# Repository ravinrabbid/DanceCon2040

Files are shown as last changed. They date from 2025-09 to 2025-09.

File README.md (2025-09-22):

# DanceCon2040 - A RP2040 based Dance Pad

DanceCon2040 is a firmware (and by extension a PCB) for arcade style Dance Pad controllers with up to nine panels.

It is pretty much tailored to this specific use case, if you are looking for something universal, ready-to-flash and on-the-fly configurable I'd recommend to have a look at more generic approaches like [GP2040-CE](https://github.com/OpenStickCommunity/GP2040-CE). If you however want build something more specialized or custom, feel free to use this project as a base, it is designed to be somewhat modular and should be easy remodel. See [DivaCon2040](https://github.com/ravinrabbid/DivaCon2040) or [DonCon2040](https://github.com/ravinrabbid/DonCon2040) for examples on how this could look like.
If you have any questions about the project in general or need hints how to build this thing, feel free to open a [discussion](https://github.com/ravinrabbid/DanceCon2040/discussions) anytime!

## Features

- Various controller emulation modes
  - Spice2x - Basic USB gamepad with support for HID lights
  - Xbox360 DDR - Emulates a Xbox360 DDR Dance Mat (untested!)
  - Xbox360
  - PS3 DDR - Emulates a Playstation 3 DDR Dance Mat
  - Dualshock 3
  - Dualshock 4 (Only for PC/Steam, does not work on an actual PS4!)
  - PS4 Compat - Works on PS4 (see [PS4 Authentication](#ps4-authentication) for details)
  - Switch Pro Controller
  - Keyboard - Two different mappings for player 1 or 2 available
  - Debug mode - Outputs current state via USB serial and allows direct flashing
- Support for either 4,5,6,8 or 9 panels for different games/game modes.
- Additional buttons via external i2c GPIO expander
- Basic configuration via on-screen menu on attached OLED screen
- WS2812 LED for panel illumination
- Steps-per-minute counter counter on display

## Building

<!-- I highly recommend to build the firmware yourself so you can make adjustments in `include/GlobalConfiguration.h` to match your specific controller build.
You can still use the [binary release](https://github.com/ravinrabbid/DanceCon2040/releases) which is pre-configured for the [DanceConIO](/pcb/DanceConIO). -->

### VSCode (Windows, Linux, MacOS)

Install [VSCode](https://code.visualstudio.com/) and get the [Raspberry Pi Pico](https://marketplace.visualstudio.com/items?itemName=raspberry-pi.raspberry-pi-pico) extension. From the extension choose 'Import Project' and select the folder where you've checked out this repository, then use 'Compile Project'.

### CLI

See [pico-sdk readme](https://github.com/raspberrypi/pico-sdk/blob/master/README.md#quick-start-your-own-project) for a list of pre-requisites.

Use the environment variables `PICO_SDK_PATH` to use a local pico-sdk, and `PICO_BOARD` to select another target board.
By default the pico-sdk will be fetched from Github and the target board will be "pico".

```sh
mkdir build && cd build
cmake ..
make
```

## Configuration

Few things which you probably want to change more regularly can be changed using an on-screen menu on the attached OLED display, hold both Start and Select for 2 seconds to enter the menu:

- Controller emulation mode
- Trigger thresholds
- Hold Time
- Hysteresis
- Calibration
- LED brightness, animation style and colors
- Reset settings to defaults
- Enter BOOTSEL mode for firmware flashing

Those settings are persisted to flash memory if you choose 'Save' when exiting the Menu and will survive power cycles.

Defaults and everything else is compiled statically into the firmware. You can find everything in `include/GlobalConfiguration.h`. This covers default controller emulation mode, i2c pins, ADC configuration, default trigger thresholds, hysteresis, debounce delay, panel mapping, LED colors and brightness.

### Debounce Delay / Hold Time / Hysteresis

The debounce delay also implicitly serves as the hold time of the input after a panel if triggered. On some platforms inputs won't be registered properly if this time is too short.
If you notice dropped inputs even if the controller signals an input on the LED/Display, try to increase this value.

Since the values read from load cells are not very stable, rapid triggering can happen right at the threshold value. If you encounter this, try to increase the hysteresis offset.
A panel will trigger if its value exceeds `threshold + hysteresis` and will un-trigger if its value drops below `thresholds - hysteresis` again.

### PS4 Authentication

The PS4 needs a controller to sign a cryptographic challenge every few seconds, otherwise it will stop working after around 8 minutes after plugging in. For rhythm games this is somewhat bearable, since you can re-plug the controller before starting each song to avoid running into the timeout during gameplay. Still, this is annoying.

DanceCon2040 can sign those challenges, but you will need to obtain some data from an original DS4 and compile it into the firmware. You will need a serial, signature and private key file. I can't and won't help you how to obtain those, you'll need to figure this out yourself.

To build the firmware run `scripts/generateAuthConfig.py` in the folder where you placed the required files. Copy the resulting `PS4AuthConfiguration.h` to the `include` directory, replacing the existing header. Then build the firmware as described in [Building](#building).

Signing the challenge will block the second core of the rp2040 for 2-3 seconds, so the display, external controller and LED will appear stuck from time to time. Input handling of the drum is unaffected.

## Hardware

### IO Board

The [DanceConIO](/pcb/DanceConIO) board in the pcb subfolder is built to be used with Wheatstone Bridge type panel sensors, e.g. load cells. It hosts a Waveshare RP2040-Zero and two or three ADS124S06 ADCs for up to nine differential inputs. See its [README](/pcb/DanceConIO/README.md) for details.

If you don't want to use this board, the firmware should be usable on most RP2040 boards with appropriate configuration. You may also use a more simple panel trigger solution, the firmware can also be configured to use the RP2040's internal ADC or simple GPIO style inputs.

### Controller Buttons and Display

Additional controller buttons and the display are attached to the same i2c bus. For the display, use a standard SSD1306 OLED display with 128x64 resolution. The buttons need to be attached to a MCP23017 IO expander.

See [DonConPad](/pcb/DonConPad/) for a exemplary gamepad pcb.

## Acknowledgements

- [daschr](https://github.com/daschr) for the [SSD1306 OLED driver](https://github.com/daschr/pico-ssd1306)
- [FeralAI](https://github.com/FeralAI) for the inspiration and Dualshock3/XInput driver from the [GP2040 Project](https://github.com/FeralAI/GP2040)
- The linux kernel contributors for documenting the game controllers in their drivers

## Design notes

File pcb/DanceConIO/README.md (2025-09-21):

# DanceConIO - A 9-Channel High-Speed Body Scale for the DanceCon2040

This board hosts a Waveshare RP2040-Zero microcontroller unit and provides up to 9 differential inputs for sensors in Wheatstone Bridge configuration. In addition it provides signal shitting for WS2812 style LEDs and break out connectors for I2C and GPIOs.

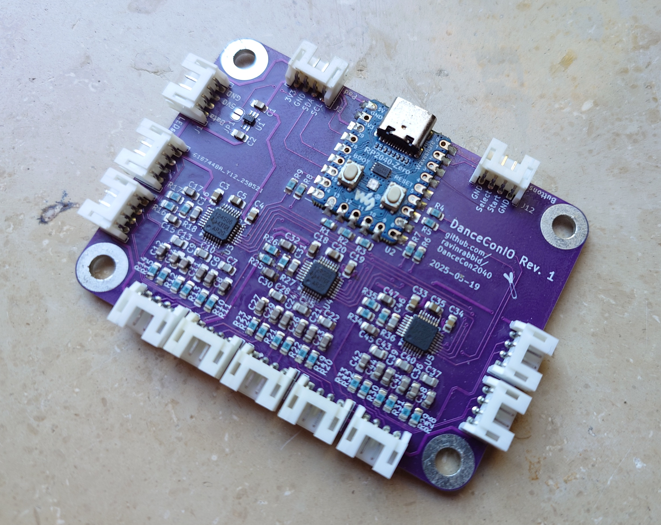
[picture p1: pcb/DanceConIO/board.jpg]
DanceConIO PCB


## Sensors

Any sensor in Wheatstone bridge configuration should work.
Tests were mainly done using a configuration of four 50kg half bridge load cells, cf. [LoadCellAdapter](../LoadCellAdapter) for wiring.
Other sensors might need adjustment of the ADC's amplifier gain within the firmware.

## Notes

- Populate either 2 or 3 of the ADC sections:
  - 4-Panel Pads need 2 ADCs.
  - 5- and 6-Panel Pads can use 2 or 3 ADCs, using 3 will increase the sample rate.
  - 8- and 9-Panel Pads need 3 ADCs.
- Populated ADCs must be configured in firmware, otherwise they will interfere with the SPI bus and prevent the other ADCs from working properly.
- If readings are too noisy you can try lowering the sample rate or using the ADC's Sinc3 filter. See table below for the example sample rates of a full scan of all panels.

### Expected Sample Rates

| Configuration<br>Filter | 2 ADCs w/ 4 Panels or 3 ADCs w/ 6 Panels ADC<br>LowLatency / Sinc3 | 2 ADCs w/ 6 Panels or 3 ADCs w/ 9 Panels ADC<br>LowLatency / Sinc3 |
| ---: | :---: | :---: |
| 4000kSPS | 1020Hz / 512Hz | 680Hz / 342Hz |
| 2000kSPS | 675Hz / 290Hz | 450Hz / 194Hz |
| 1000kSPS | 403Hz / 155Hz | 270Hz / 103Hz |
| 800kSPS | 335Hz / 122Hz | 223Hz / 82Hz |
| 400kSPS | 182Hz / 64Hz | 122Hz / 42Hz |
| 200kSPS | 95Hz / 32Hz | 63Hz / 22Hz |
| 100kSPS | 48Hz / 16Hz | 32Hz / - |

## Bill of Materials

| **Reference** | **Description** | **Digikey Part** | **Notes** |
| --- | :---: | :---: | :---: |
| U1 | 74LVC1T45 Dual supply translating transceiver | 1727-4560-1-ND | Can be omitted if you don't need level shifting, bridge JP1 in this case |
| U2 | Waveshare RP2040-Zero | - | |
| U3, U4, U5 | ADS124S06 24bit Delta-Sigma ADC | 296-45169-1-ND | |
| C1, C2, C4, C19, C34 | 0.1µF SMD Ceramic Capacitor | 1276-1003-1-ND | |
| C3, C18, C33 | 330nF SMD Ceramic Capacitor | 1276-1123-1-ND | |
| C5, C20, C35 | 1µF SMD Ceramic Capacitor | 1276-1029-1-ND | |
| C6, C8, C9, C11, C12, C14, C15, C17, C21, C23, C24, C26, C27, C29, C30, C32, C36, C38, C39, C41, C42, C44, C45, C47 | 2.2nF C0G/NP0 SMD Ceramic Capacitor | 1276-2993-1-ND | |
| C7, C10, C13, C16, C22, C25, C28, C31, C37, C40, C43, C46 | 22nF C0G/NP0 SMD Ceramic Capacitor | 490-GRM2165C1H223JA01DCT-ND | |
| R1-R9 | 47Ω SMD Resistor |  2019-RK73H2ATTD47R0FCT-ND  | |
| R10-R17, R19-R26, R28-R35 | 150Ω SMD Resistor |  2019-RK73H2ATTD1500FCT-ND  | |
| R18, R27, R36 | 100kΩ SMD Resistor |  2019-RK73H2ATTD1003FCT-ND  | |
| J1-J12 | 4Pin S5B-PH-K-S Connector | 455-1721-ND | PHR-4 plus SPH-002T-P0.5L is the counterpart |

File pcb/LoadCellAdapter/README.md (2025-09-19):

# LoadCellAdapter

A simple passive adapter pcb to combine four 3-Wire half bridge load cells into a Wheatstone bridge configuration.

## Bill of Materials

| **Reference** | **Description** | **Digikey Part** | **Notes** |
| --- | :---: | :---: | :---: |
| J1, J2, J3, J4, J5 | 4Pin S4B-PH-K-S Connector | 455-1721-ND | Optional, wires can also be soldered directly to the board.</br>PHR-4 plus SPH-002T-P0.5L is the counterpart |

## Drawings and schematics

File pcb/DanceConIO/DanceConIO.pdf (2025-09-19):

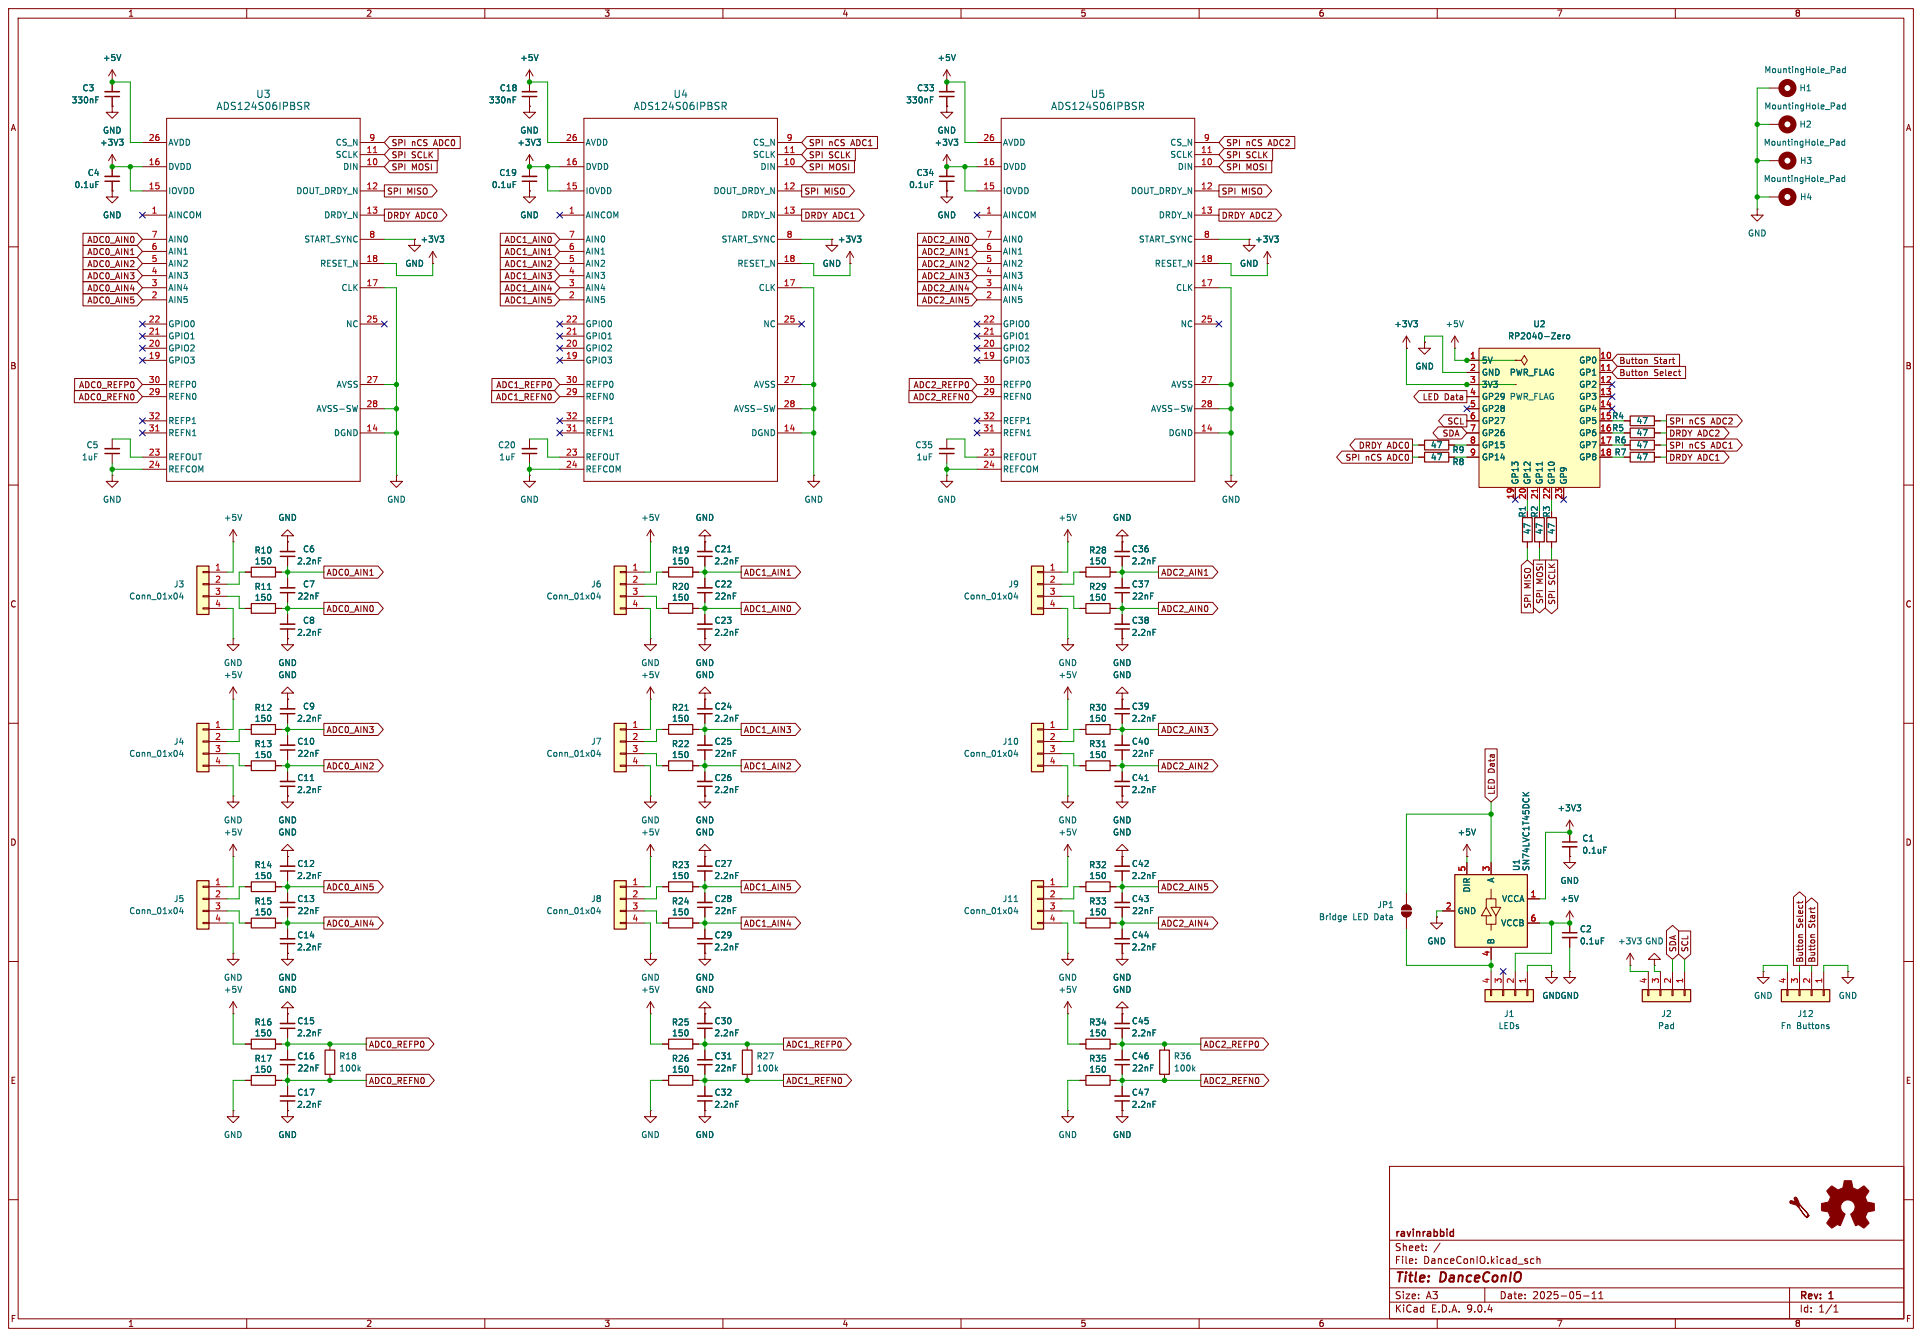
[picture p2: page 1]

SPI nCS ADC2 SPI nCS ADC1 DRDY ADC1 DRDY ADC2 SPI nCS ADC2 ADC2_AIN0 ADC0_AIN4

SPI MOSI SPI nCS ADC0 SPI MISO
SPI MOSI ADC2_AIN0 ADC2_AIN3 ADC2_AIN5 ADC2_AIN4 ADC2_AIN2 ADC2_AIN1 SPI SCLK

Button Start SPI SCLK

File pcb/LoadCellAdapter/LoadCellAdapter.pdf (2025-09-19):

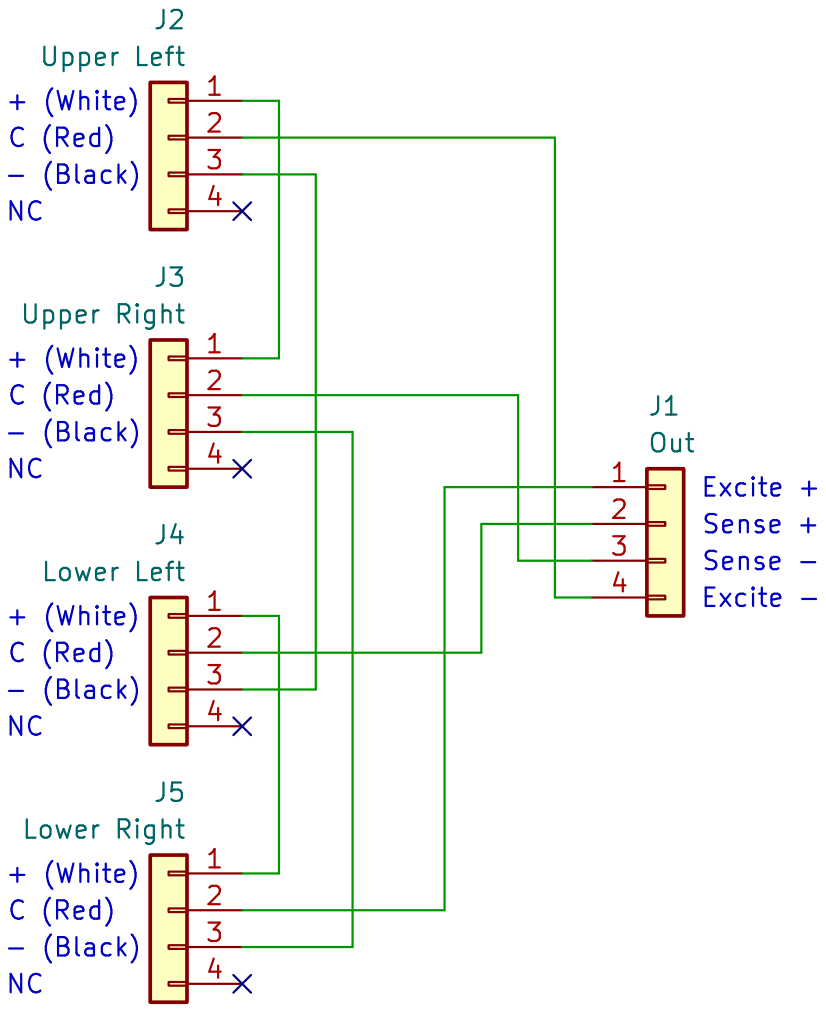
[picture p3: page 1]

Id: 1/1 Title: LoadCellAdapter File: LoadCellAdapter.kicad_sch Sheet: / ravinrabbid 1234

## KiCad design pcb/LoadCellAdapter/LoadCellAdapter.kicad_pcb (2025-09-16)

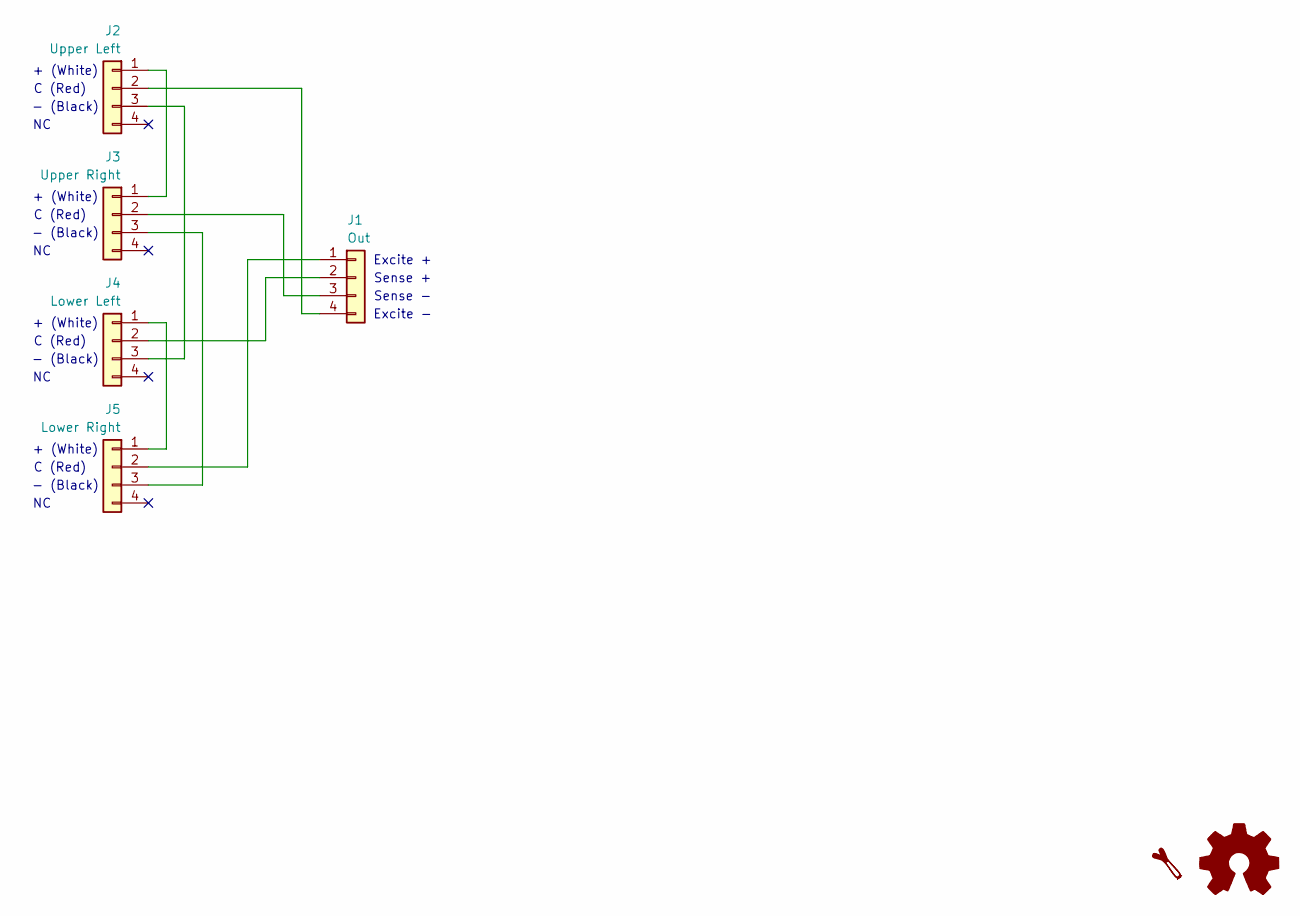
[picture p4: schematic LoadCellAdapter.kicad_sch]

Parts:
J1: Out; JST_PH_S4B-PH-K_1x04_P2.00mm_Horizontal
J2: Upper Left; JST_PH_S4B-PH-K_1x04_P2.00mm_Horizontal
J3: Upper Right; JST_PH_S4B-PH-K_1x04_P2.00mm_Horizontal
J4: Lower Left; JST_PH_S4B-PH-K_1x04_P2.00mm_Horizontal
J5: Lower Right; JST_PH_S4B-PH-K_1x04_P2.00mm_Horizontal

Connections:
unnamed: J1.1, J5.2
unnamed: J1.2, J4.2
unnamed: J1.3, J3.2
unnamed: J1.4, J2.2
unnamed: J2.1, J3.1
unnamed: J2.3, J4.3
unnamed: J3.3, J5.3
unnamed: J4.1, J5.1

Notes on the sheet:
+ (White)
Excite +
- (Black)
Excite -
C (Red)
Sense -
Sense +

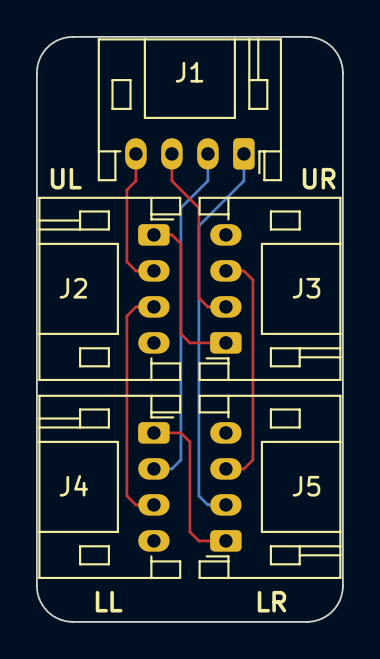
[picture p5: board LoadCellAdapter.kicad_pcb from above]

Board: 2 copper layers, 17.0 x 32.5 mm, 5 parts (0 on the bottom side), 8 nets.

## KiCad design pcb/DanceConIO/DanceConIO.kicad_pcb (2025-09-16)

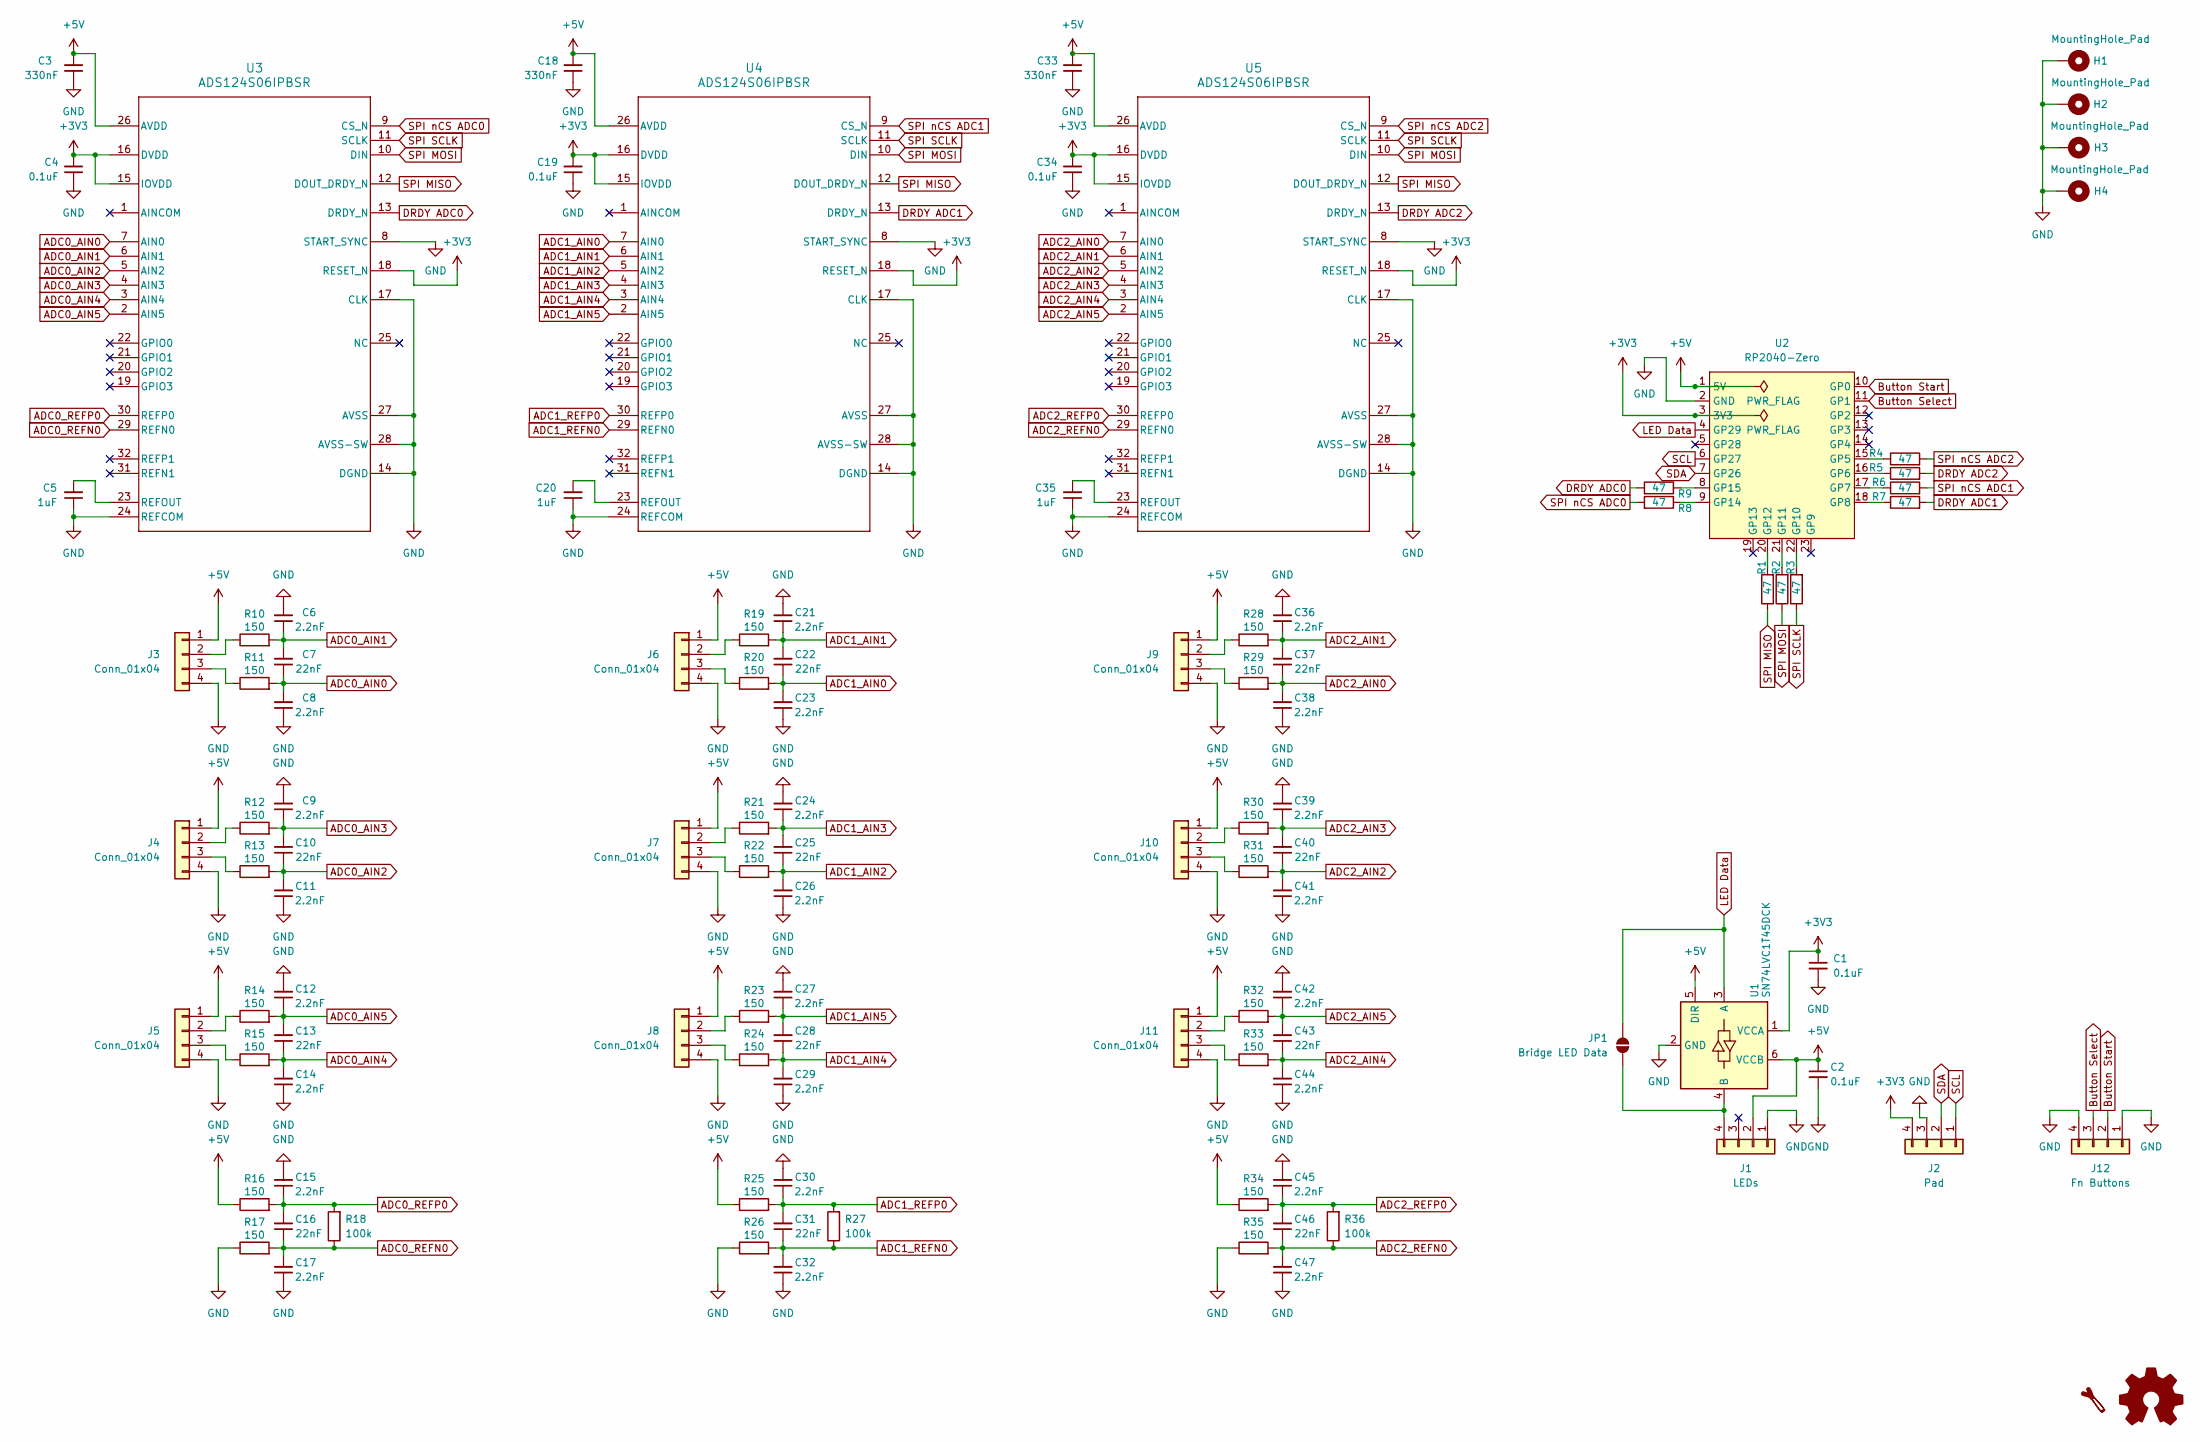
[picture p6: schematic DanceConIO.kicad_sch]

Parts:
C1, C2, C4, C19, C34: 0.1uF; C_0805_2012Metric_Pad1.18x1.45mm_HandSolder
C3, C18, C33: 330nF; C_0805_2012Metric_Pad1.18x1.45mm_HandSolder
C5, C20, C35: 1uF; C_0805_2012Metric_Pad1.18x1.45mm_HandSolder
C6, C8, C9, C11, C12, C14, C15, C17, C21, C23, C24, C26, C27, C29, C30, C32, C36, C38, C39, C41, C42, C44, C45, C47: 2.2nF; C_0805_2012Metric_Pad1.18x1.45mm_HandSolder
C7, C10, C13, C16, C22, C25, C28, C31, C37, C40, C43, C46: 22nF; C_0805_2012Metric_Pad1.18x1.45mm_HandSolder
H1, H2, H3, H4: MountingHole_Pad; MountingHole_4.5mm_Pad_TopOnly
J1: LEDs; JST_PH_S4B-PH-K_1x04_P2.00mm_Horizontal
J2: Pad; JST_PH_S4B-PH-K_1x04_P2.00mm_Horizontal
J3, J4, J5, J6, J7, J8, J9, J10, J11: Conn_01x04; JST_PH_S4B-PH-K_1x04_P2.00mm_Horizontal
J12: Fn Buttons; JST_PH_S4B-PH-K_1x04_P2.00mm_Horizontal
JP1: Bridge LED Data; SolderJumper-2_P1.3mm_Open_RoundedPad1.0x1.5mm
R1, R2, R3, R4, R5, R6, R7, R8, R9: 47; R_0805_2012Metric_Pad1.20x1.40mm_HandSolder
R10, R11, R12, R13, R14, R15, R16, R17, R19, R20, R21, R22, R23, R24, R25, R26, R28, R29, R30, R31, R32, R33, R34, R35: 150; R_0805_2012Metric_Pad1.20x1.40mm_HandSolder
R18, R27, R36: 100k; R_0805_2012Metric_Pad1.20x1.40mm_HandSolder
U1: SN74LVC1T45DCK; SOT-363_SC-70-6_Handsoldering
U2: RP2040-Zero; RP2040 Zero
U3, U4, U5: ADS124S06IPBSR; PQFP-32_5x5mm_P0.5mm

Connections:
+3V3: C1.1, C4.2, C19.2, C34.2, J2.4, U1.1 (VCCA), U2.3 (3V3), U3.15 (IOVDD), U3.16 (DVDD), U3.18 (RESET_N), U4.15 (IOVDD), U4.16 (DVDD), U4.18 (RESET_N), U5.15 (IOVDD), U5.16 (DVDD), U5.18 (RESET_N)
+5V: C2.1, C3.2, C18.2, C33.2, J1.2, J3.1, J4.1, J5.1, J6.1, J7.1, J8.1, J9.1, J10.1, J11.1, R16.1, R25.1, R34.1, U1.5 (DIR), U1.6 (VCCB), U2.1 (5V), U3.26 (AVDD), U4.26 (AVDD), U5.26 (AVDD)
ADC0_AIN0: C7.1, C8.2, R11.2, U3.7 (AIN0)
ADC0_AIN1: C6.1, C7.2, R10.2, U3.6 (AIN1)
ADC0_AIN2: C10.1, C11.2, R13.2, U3.5 (AIN2)
ADC0_AIN3: C9.1, C10.2, R12.2, U3.4 (AIN3)
ADC0_AIN4: C13.1, C14.2, R15.2, U3.3 (AIN4)
ADC0_AIN5: C12.1, C13.2, R14.2, U3.2 (AIN5)
ADC0_REFN0: C16.1, C17.2, R17.2, R18.1, U3.29 (REFN0)
ADC0_REFP0: C15.1, C16.2, R16.2, R18.2, U3.30 (REFP0)
ADC1_AIN0: C22.1, C23.2, R20.2, U4.7 (AIN0)
ADC1_AIN1: C21.1, C22.2, R19.2, U4.6 (AIN1)
ADC1_AIN2: C25.1, C26.2, R22.2, U4.5 (AIN2)
ADC1_AIN3: C24.1, C25.2, R21.2, U4.4 (AIN3)
ADC1_AIN4: C28.1, C29.2, R24.2, U4.3 (AIN4)
ADC1_AIN5: C27.1, C28.2, R23.2, U4.2 (AIN5)
ADC1_REFN0: C31.1, C32.2, R26.2, R27.1, U4.29 (REFN0)
ADC1_REFP0: C30.1, C31.2, R25.2, R27.2, U4.30 (REFP0)
ADC2_AIN0: C37.1, C38.2, R29.2, U5.7 (AIN0)
ADC2_AIN1: C36.1, C37.2, R28.2, U5.6 (AIN1)
ADC2_AIN2: C40.1, C41.2, R31.2, U5.5 (AIN2)
ADC2_AIN3: C39.1, C40.2, R30.2, U5.4 (AIN3)
ADC2_AIN4: C43.1, C44.2, R33.2, U5.3 (AIN4)
ADC2_AIN5: C42.1, C43.2, R32.2, U5.2 (AIN5)
ADC2_REFN0: C46.1, C47.2, R35.2, R36.1, U5.29 (REFN0)
ADC2_REFP0: C45.1, C46.2, R34.2, R36.2, U5.30 (REFP0)
Button Select: J12.3, U2.11 (GP1)
Button Start: J12.2, U2.10 (GP0)
DRDY ADC0: R9.2, U3.13 (DRDY_N)
DRDY ADC1: R7.2, U4.13 (DRDY_N)
DRDY ADC2: R5.2, U5.13 (DRDY_N)
GND: C1.2, C2.2, C3.1, C4.1, C5.1, C6.2, C8.1, C9.2, C11.1, C12.2, C14.1, C15.2, C17.1, C18.1, C19.1, C20.1, C21.2, C23.1, C24.2, C26.1, C27.2, C29.1, C30.2, C32.1, C33.1, C34.1, C35.1, C36.2, C38.1, C39.2, C41.1, C42.2, C44.1, C45.2, C47.1, H1.1, H2.1, H3.1, H4.1, J1.1, J2.3, J3.4, J4.4, J5.4, J6.4, J7.4, J8.4, J9.4, J10.4, J11.4, J12.1, J12.4, R17.1, R26.1, R35.1, U1.2 (GND), U2.2 (GND), U3.8 (START_SYNC), U3.14 (DGND), U3.17 (CLK), U3.24 (REFCOM), U3.27 (AVSS), U3.28 (AVSS-SW), U4.8 (START_SYNC), U4.14 (DGND), U4.17 (CLK), U4.24 (REFCOM), U4.27 (AVSS), U4.28 (AVSS-SW), U5.8 (START_SYNC), U5.14 (DGND), U5.17 (CLK), U5.24 (REFCOM), U5.27 (AVSS), U5.28 (AVSS-SW)
LED Data: JP1.1 (A), U1.3 (A), U2.4 (GP29)
unnamed: J1.4, JP1.2 (B), U1.4 (B)
unnamed: J3.2, R10.1
unnamed: J3.3, R11.1
unnamed: J4.2, R12.1
unnamed: J4.3, R13.1
unnamed: J5.2, R14.1
unnamed: J5.3, R15.1
unnamed: J6.2, R19.1
unnamed: J6.3, R20.1
unnamed: J7.2, R21.1
unnamed: J7.3, R22.1
unnamed: J8.2, R23.1
unnamed: J8.3, R24.1
unnamed: J9.2, R28.1
unnamed: J9.3, R29.1
unnamed: J10.2, R30.1
unnamed: J10.3, R31.1
unnamed: J11.2, R32.1
unnamed: J11.3, R33.1
unnamed: R4.1, U2.15 (GP5)
unnamed: R5.1, U2.16 (GP6)
unnamed: R6.1, U2.17 (GP7)
unnamed: R7.1, U2.18 (GP8)
unnamed: R3.2, U2.22 (GP10)
unnamed: R2.2, U2.21 (GP11)
unnamed: R1.2, U2.20 (GP12)
unnamed: R8.1, U2.9 (GP14)
unnamed: R9.1, U2.8 (GP15)
unnamed: C5.2, U3.23 (REFOUT)
unnamed: C20.2, U4.23 (REFOUT)
unnamed: C35.2, U5.23 (REFOUT)
SCL: J2.1, U2.6 (GP27)
SDA: J2.2, U2.7 (GP26)
SPI MISO: R1.1, U3.12 (DOUT_DRDY_N), U4.12 (DOUT_DRDY_N), U5.12 (DOUT_DRDY_N)
SPI MOSI: R2.1, U3.10 (DIN), U4.10 (DIN), U5.10 (DIN)
SPI SCLK: R3.1, U3.11 (SCLK), U4.11 (SCLK), U5.11 (SCLK)
SPI nCS ADC0: R8.2, U3.9 (CS_N)
SPI nCS ADC1: R6.2, U4.9 (CS_N)
SPI nCS ADC2: R4.2, U5.9 (CS_N)

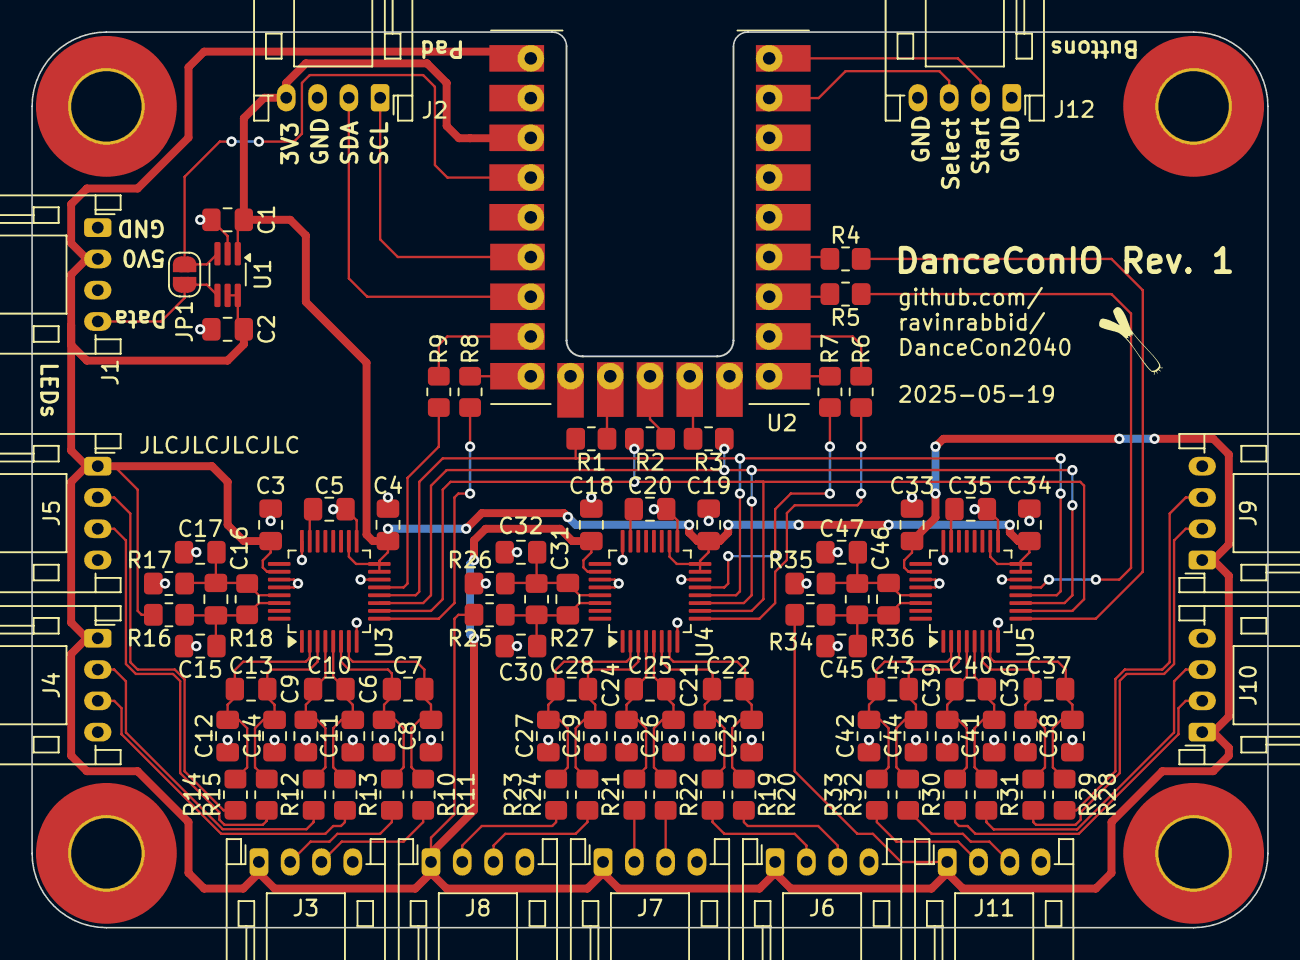
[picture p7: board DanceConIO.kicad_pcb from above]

Board: 2 copper layers, 79.0 x 57.2 mm, 105 parts (0 on the bottom side), 72 nets.

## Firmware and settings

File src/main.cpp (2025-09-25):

#include "peripherals/Controller.h"
#include "peripherals/Display.h"
#include "peripherals/PadButtons.h"
#include "usb/device/hid/ps4_auth.h"
#include "usb/device_driver.h"
#include "utils/InputReport.h"
#include "utils/InputState.h"
#include "utils/Menu.h"
#include "utils/PS4AuthProvider.h"
#include "utils/SettingsStore.h"

#include "GlobalConfiguration.h"
#include "PS4AuthConfiguration.h"

#include "pico/multicore.h"
#include "pico/util/queue.h"

#include <cstdio>

using namespace Dancecon;

namespace {

queue_t control_queue;
queue_t menu_display_queue;
queue_t pad_input_queue;
queue_t controller_input_queue;
queue_t panel_led_queue;

queue_t auth_challenge_queue;
queue_t auth_signed_challenge_queue;

enum class ControlCommand : uint8_t {
    SetUsbMode,
    SetPlayerLed,
    SetLedBrightness,
    SetLedAnimationSpeed,
    SetLedIdleMode,
    SetLedIdleColors,
    SetLedActiveMode,
    SetLedActiveColors,
    SetLedEnablePlayerColor,
    EnterMenu,
    ExitMenu,
};

struct ControlMessage {
    ControlCommand command;
    union {
        usb_mode_t usb_mode;
        usb_player_led_t player_led;
        uint8_t led_brightness;
        uint8_t led_animation_speed;
        Peripherals::PanelLeds<Config::Default::led_config.PANEL_COUNT>::Config::IdleMode led_idle_mode;
        Peripherals::PanelLeds<Config::Default::led_config.PANEL_COUNT>::Config::PanelColors led_idle_colors;
        Peripherals::PanelLeds<Config::Default::led_config.PANEL_COUNT>::Config::ActiveMode led_active_mode;
        Peripherals::PanelLeds<Config::Default::led_config.PANEL_COUNT>::Config::PanelColors led_active_colors;
        bool led_enable_player_color;
    } data;
};

void core1_task() {
    multicore_lockout_victim_init();

    // Init i2c port here because Controller and Display share it and
    // therefore can't init it themself.
    gpio_set_function(Config::Default::i2c_config.sda_pin, GPIO_FUNC_I2C);
    gpio_set_function(Config::Default::i2c_config.scl_pin, GPIO_FUNC_I2C);
    gpio_pull_up(Config::Default::i2c_config.sda_pin);
    gpio_pull_up(Config::Default::i2c_config.scl_pin);
    i2c_init(Config::Default::i2c_config.block, Config::Default::i2c_config.speed_hz);

    const Peripherals::StatusLed status_led(Config::Default::status_led_config);
    Peripherals::Controller controller(Config::Default::controller_config);
    Peripherals::PanelLeds<Config::Default::led_config.PANEL_COUNT> led(Config::Default::led_config);
    Peripherals::Display display(Config::Default::display_config);

    Utils::PS4AuthProvider ps4authprovider;
    std::array<uint8_t, Utils::PS4AuthProvider::SIGNATURE_LENGTH> auth_challenge{};

    Utils::InputState input_state{};
    Utils::MenuState menu_display_msg{};
    ControlMessage control_msg{};
    usb_panel_led_t panel_led{};

    while (true) {
        controller.updateInputState(input_state);

        queue_try_add(&controller_input_queue, &input_state.controller);
        queue_try_remove(&pad_input_queue, &input_state.pad);

        if (queue_try_remove(&panel_led_queue, &panel_led)) {
            led.update(panel_led);
        }

        if (queue_try_remove(&control_queue, &control_msg)) {
            switch (control_msg.command) {
            case ControlCommand::SetUsbMode:
                display.setUsbMode(control_msg.data.usb_mode);
                break;
            case ControlCommand::SetPlayerLed:
                status_led.setPlayer(control_msg.data.player_led);

                switch (control_msg.data.player_led.type) {
                case USB_PLAYER_LED_ID:
                    display.setPlayerId(control_msg.data.player_led.id);
                    break;
                case USB_PLAYER_LED_COLOR:
                    led.setPlayerColor({.r = control_msg.data.player_led.red,
                                        .g = control_msg.data.player_led.green,
                                        .b = control_msg.data.player_led.blue});
                    break;
                }
                break;
            case ControlCommand::SetLedBrightness:
                led.setBrightness(control_msg.data.led_brightness);
                break;
            case ControlCommand::SetLedAnimationSpeed:
                led.setAnimationSpeed(control_msg.data.led_animation_speed);
                break;
            case ControlCommand::SetLedIdleMode:
                led.setIdleMode(control_msg.data.led_idle_mode);
                break;
            case ControlCommand::SetLedIdleColors:
                led.setIdleColors(control_msg.data.led_idle_colors);
                break;
            case ControlCommand::SetLedActiveMode:
                led.setActiveMode(control_msg.data.led_active_mode);
                break;
            case ControlCommand::SetLedActiveColors:
                led.setActiveColors(control_msg.data.led_active_colors);
                break;
            case ControlCommand::SetLedEnablePlayerColor:
                led.setEnablePlayerColor(control_msg.data.led_enable_player_color);
                break;
            case ControlCommand::EnterMenu:
                display.showMenu();
                break;
            case ControlCommand::ExitMenu:
                display.showIdle();
                break;
            }
        }
        if (queue_try_remove(&menu_display_queue, &menu_display_msg)) {
            display.setMenuState(menu_display_msg);
        }
        if (queue_try_remove(&auth_challenge_queue, auth_challenge.data())) {
            const auto signed_challenge = ps4authprovider.sign(auth_challenge);
            queue_try_remove(&auth_signed_challenge_queue, nullptr); // clear queue first
            queue_try_add(&auth_signed_challenge_queue, &signed_challenge);
        }

        led.setInputState(input_state);
        display.setInputState(input_state);

        led.update();
        display.update();
    }
}

} // namespace

int main() {
    queue_init(&control_queue, sizeof(ControlMessage), 1);
    queue_init(&menu_display_queue, sizeof(Utils::MenuState), 1);
    queue_init(&pad_input_queue, sizeof(Utils::InputState::Pad), 1);
    queue_init(&controller_input_queue, sizeof(Utils::InputState::Controller), 1);
    queue_init(&panel_led_queue, sizeof(usb_panel_led_t), 1);
    queue_init(&auth_challenge_queue, sizeof(std::array<uint8_t, Utils::PS4AuthProvider::SIGNATURE_LENGTH>), 1);
    queue_init(&auth_signed_challenge_queue, sizeof(std::array<uint8_t, Utils::PS4AuthProvider::SIGNATURE_LENGTH>), 1);

    Utils::InputState input_state{};
    Utils::InputReport input_report;

    std::array<uint8_t, Utils::PS4AuthProvider::SIGNATURE_LENGTH> auth_challenge_response{};

    auto settings_store = std::make_shared<
        Utils::SettingsStore<Config::Default::pad_config.PANEL_COUNT, Config::Default::led_config.PANEL_COUNT>>();
    const auto mode = settings_store->getUsbMode();

    Peripherals::PadButtons pad_buttons(Config::Default::pad_buttons_config);
    Peripherals::Pad<Config::Default::pad_config.PANEL_COUNT> pad(Config::Default::pad_config);
    Utils::Menu menu(settings_store, [&pad]() { pad.calibrate(); });

    multicore_launch_core1(core1_task);

    usbd_driver_init(mode);
    usbd_driver_set_player_led_cb([](usb_player_led_t player_led) {
        const auto ctrl_message =
            ControlMessage{.command = ControlCommand::SetPlayerLed, .data = {.player_led = player_led}};
        queue_try_add(&control_queue, &ctrl_message);
    });
    usbd_driver_set_panel_led_cb([](usb_panel_led_t panel_led) { queue_try_add(&panel_led_queue, &panel_led); });

    if (Config::PS4Auth::config.enabled) {
        ps4_auth_init(Config::PS4Auth::config.key_pem.c_str(), Config::PS4Auth::config.key_pem.size() + 1,
                      Config::PS4Auth::config.serial.data(), Config::PS4Auth::config.signature.data(),
                      [](const uint8_t *challenge) { queue_try_add(&auth_challenge_queue, challenge); });
    }

    stdio_init_all();

    const auto readSettings = [&]() {
        const auto sendCtrlMessage = [&](const ControlMessage &msg) { queue_add_blocking(&control_queue, &msg); };

        sendCtrlMessage({.command = ControlCommand::SetUsbMode, .data = {.usb_mode = mode}});
        sendCtrlMessage({.command = ControlCommand::SetLedBrightness,
                         .data = {.led_brightness = settings_store->getLedBrightness()}});
        sendCtrlMessage({.command = ControlCommand::SetLedAnimationSpeed,
                         .data = {.led_animation_speed = settings_store->getLedAnimationSpeed()}});
        sendCtrlMessage(
            {.command = ControlCommand::SetLedIdleMode, .data = {.led_idle_mode = settings_store->getLedIdleMode()}});
        sendCtrlMessage({.command = ControlCommand::SetLedIdleColors,
                         .data = {.led_idle_colors = settings_store->getLedIdleColors()}});
        sendCtrlMessage({.command = ControlCommand::SetLedActiveMode,
                         .data = {.led_active_mode = settings_store->getLedActiveMode()}});
        sendCtrlMessage({.command = ControlCommand::SetLedActiveColors,
                         .data = {.led_active_colors = settings_store->getLedActiveColors()}});
        sendCtrlMessage({.command = ControlCommand::SetLedEnablePlayerColor,
                         .data = {.led_enable_player_color = settings_store->getLedEnablePlayerColor()}});

        pad.setDebounceDelay(settings_store->getDebounceDelay());
        pad.setThresholds(settings_store->getTriggerThresholds());
        pad.setHysteresis(settings_store->getHysteresis());
    };

    readSettings();

    pad.calibrate();

    while (true) {
        pad_buttons.updateInputState(input_state);
        pad.updateInputState(input_state);
        queue_try_remove(&controller_input_queue, &input_state.controller);

        const auto pad_message = input_state.pad;

        if (menu.active()) {
            menu.update(input_state.controller);
            if (menu.active()) {
                const auto display_msg = menu.getState();
                queue_add_blocking(&menu_display_queue, &display_msg);
            } else {
                settings_store->store();

                ControlMessage ctrl_message = {.command = ControlCommand::ExitMenu, .data = {}};
                queue_add_blocking(&control_queue, &ctrl_message);
            }

            readSettings();
            input_state.releaseAll();

        } else if (input_state.checkHotkey()) {
            menu.activate();

            ControlMessage ctrl_message{.command = ControlCommand::EnterMenu, .data = {}};
            queue_add_blocking(&control_queue, &ctrl_message);
        }

        usbd_driver_send_report(input_report.getUsbReport(input_state, mode));
        usbd_driver_task();

        queue_try_add(&pad_input_queue, &pad_message);

        if (queue_try_remove(&auth_signed_challenge_queue, auth_challenge_response.data())) {
            ps4_auth_set_signed_challenge(auth_challenge_response.data());
        }
    }

    return 0;
}

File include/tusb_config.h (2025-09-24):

#ifndef TUSB_CONFIG_H_
#define TUSB_CONFIG_H_

#ifdef __cplusplus
extern "C" {
#endif

//--------------------------------------------------------------------+
// Board Specific Configuration
//--------------------------------------------------------------------+

// RHPort number used for device can be defined by board.mk, default to port 0
#ifndef BOARD_TUD_RHPORT
#define BOARD_TUD_RHPORT (0)
#endif

// RHPort max operational speed can defined by board.mk
#ifndef BOARD_TUD_MAX_SPEED
#define BOARD_TUD_MAX_SPEED OPT_MODE_DEFAULT_SPEED
#endif

#define CFG_TUSB_RHPORT0_MODE OPT_MODE_DEVICE

//--------------------------------------------------------------------
// COMMON CONFIGURATION
//--------------------------------------------------------------------

#ifndef CFG_TUSB_DEBUG
#define CFG_TUSB_DEBUG (0)
#endif

// Enable Device stack
#define CFG_TUD_ENABLED (1)

// Default is max speed that hardware controller could support with on-chip PHY
#define CFG_TUD_MAX_SPEED BOARD_TUD_MAX_SPEED

//--------------------------------------------------------------------
// DEVICE CONFIGURATION
//--------------------------------------------------------------------

#ifndef CFG_TUD_ENDPOINT0_SIZE
#define CFG_TUD_ENDPOINT0_SIZE (64)
#endif

//------------- CLASS -------------//
#define CFG_TUD_CDC (1)
#define CFG_TUD_MSC (0)
#define CFG_TUD_MIDI (0)
#define CFG_TUD_HID (1)
#define CFG_TUD_VENDOR (0)

// Device class buffer sizes
#define CFG_TUD_CDC_RX_BUFSIZE (TUD_OPT_HIGH_SPEED ? 512 : 64)
#define CFG_TUD_CDC_TX_BUFSIZE (TUD_OPT_HIGH_SPEED ? 512 : 64)
#define CFG_TUD_CDC_EP_BUFSIZE (TUD_OPT_HIGH_SPEED ? 512 : 64)

#define CFG_TUD_HID_EP_BUFSIZE (64) // NOLINT(cppcoreguidelines-macro-to-enum,modernize-macro-to-enum)

#ifdef __cplusplus
}
#endif

#endif // TUSB_CONFIG_H_

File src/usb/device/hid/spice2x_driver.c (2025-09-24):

#include "usb/device/hid/spice2x_driver.h"

#include "usb/device/hid/common.h"

#include "tusb.h"

const tusb_desc_device_t spice2x_desc_device = {
    .bLength = sizeof(tusb_desc_device_t),
    .bDescriptorType = TUSB_DESC_DEVICE,
    .bcdUSB = 0x0200,
    .bDeviceClass = TUSB_CLASS_UNSPECIFIED,
    .bDeviceSubClass = 0x00,
    .bDeviceProtocol = 0x00,
    .bMaxPacketSize0 = CFG_TUD_ENDPOINT0_SIZE,
    .idVendor = 0x1209,
    .idProduct = 0x39DD,
    .bcdDevice = 0x0100,
    .iManufacturer = USBD_STR_MANUFACTURER,
    .iProduct = USBD_STR_PRODUCT,
    .iSerialNumber = USBD_STR_SERIAL,
    .bNumConfigurations = 1,
};

enum {
    USBD_ITF_HID,
    USBD_ITF_MAX,
};

const uint8_t spice2x_desc_hid_report[] = {
    0x05, 0x01, // Usage Page (Generic Desktop Ctrls)
    0x09, 0x05, // Usage (Game Pad)
    0xA1, 0x01, // Collection (Application)
    0xA1, 0x02, //   Collection (Logical)
    0x85, 0x01, //     Report ID (1)
    0x09, 0x39, //   Usage (Hat switch)
    0x75, 0x04, //   Report Size (4)
    0x95, 0x01, //   Report Count (1)
    0x15, 0x00, //   Logical Minimum (0)
    0x25, 0x07, //   Logical Maximum (7)
    0x35, 0x00, //   Physical Minimum (0)
    0x46, 0x3B, //
    0x01,       //   Physical Maximum (315)
    0x65, 0x14, //   Unit (System: English Rotation, Length: Centimeter)
    0x81, 0x42, //   Input (Data,Var,Abs,No Wrap,Linear,Preferred State,Null State)
    0x05, 0x09, //     Usage Page (Button)
    0x75, 0x01, //     Report Size (1)
    0x95, 0x0A, //     Report Count (10)
    0x19, 0x01, //     Usage Minimum (0x01)
    0x29, 0x0A, //     Usage Maximum (0x0A)
    0x15, 0x00, //     Logical Minimum (0)
    0x25, 0x01, //     Logical Maximum (1)
    0x35, 0x00, //     Physical Minimum (0)
    0x45, 0x01, //     Physical Maximum (1)
    0x81, 0x02, //     Input (Data,Var,Abs,No Wrap,Linear,Preferred State,No Null Position)
    0x75, 0x01, //     Report Size (1)
    0x95, 0x02, //     Report Count (2)
    0x81, 0x03, //     Input (Const,Var,Abs,No Wrap,Linear,Preferred State,No Null Position)
    0x05, 0x09, //     Usage Page (Button)
    0x75, 0x01, //     Report Size (1)
    0x95, 0x0B, //     Report Count (11)
    0x19, 0x0B, //     Usage Minimum (0x0B)
    0x29, 0x15, //     Usage Maximum (0x15)
    0x15, 0x00, //     Logical Minimum (0)
    0x25, 0x01, //     Logical Maximum (1)
    0x35, 0x00, //     Physical Minimum (0)
    0x45, 0x01, //     Physical Maximum (1)
    0x81, 0x02, //     Input (Data,Var,Abs,No Wrap,Linear,Preferred State,No Null Position)
    0x75, 0x01, //     Report Size (1)
    0x95, 0x05, //     Report Count (5)
    0x81, 0x03, //     Input (Const,Var,Abs,No Wrap,Linear,Preferred State,No Null Position)
    0xC0,       //   End Collection

    0xA1, 0x02, //   Collection (Logical)
    0x85, 0x02, //     Report ID (2)
    0x15, 0x00, //     Logical Minimum (0)
    0x26, 0xFF, //
    0x00,       //     Logical Maximum (255)
    0x35, 0x00, //     Physical Minimum (0)
    0x46, 0xFF, //
    0x00,       //     Physical Maximum (1)

    0x05, 0x0A,                 //     Usage Page (Ordinal)
    0x09, 0x01,                 //     Usage (0x01)
    0xA1, 0x02,                 //     Collection (Logical)
    0x05, 0x08,                 //       Usage Page (LEDs)
    0x09, 0x4B,                 //       Usage (Generic Indicator)
    0x79, USBD_STR_LED_UP_LEFT, //       String Index
    0x75, 0x08,                 //       Report Size (8)
    0x95, 0x01,                 //       Report Count (1)
    0x91, 0x02, //       Output (Data,Var,Abs,No Wrap,Linear,Preferred State,No Null Position,Non-volatile)
    0xC0,       //     End Collection

    0x05, 0x0A,            //     Usage Page (Ordinal)
    0x09, 0x02,            //     Usage (0x02)
    0xA1, 0x02,            //     Collection (Logical)
    0x05, 0x08,            //       Usage Page (LEDs)
    0x09, 0x4B,            //       Usage (Generic Indicator)
    0x79, USBD_STR_LED_UP, //       String Index
    0x75, 0x08,            //       Report Size (8)
    0x95, 0x01,            //       Report Count (1)
    0x91, 0x02,            //       Output (Data,Var,Abs,No Wrap,Linear,Preferred State,No Null Position,Non-volatile)
    0xC0,                  //     End Collection

    0x05, 0x0A,                  //     Usage Page (Ordinal)
    0x09, 0x03,                  //     Usage (0x03)
    0xA1, 0x02,                  //     Collection (Logical)
    0x05, 0x08,                  //       Usage Page (LEDs)
    0x09, 0x4B,                  //       Usage (Generic Indicator)
    0x79, USBD_STR_LED_UP_RIGHT, //       String Index
    0x75, 0x08,                  //       Report Size (8)
    0x95, 0x01,                  //       Report Count (1)
    0x91, 0x02, //       Output (Data,Var,Abs,No Wrap,Linear,Preferred State,No Null Position,Non-volatile)
    0xC0,       //     End Collection

    0x05, 0x0A,              //     Usage Page (Ordinal)
    0x09, 0x04,              //     Usage (0x04)
    0xA1, 0x02,              //     Collection (Logical)
    0x05, 0x08,              //       Usage Page (LEDs)
    0x09, 0x4B,              //       Usage (Generic Indicator)
    0x79, USBD_STR_LED_LEFT, //       String Index
    0x75, 0x08,              //       Report Size (8)
    0x95, 0x01,              //       Report Count (1)
    0x91, 0x02,              //       Output (Data,Var,Abs,No Wrap,Linear,Preferred State,No Null Position,Non-volatile)
    0xC0,                    //     End Collection

    0x05, 0x0A,                //     Usage Page (Ordinal)
    0x09, 0x05,                //     Usage (0x05)
    0xA1, 0x02,                //     Collection (Logical)
    0x05, 0x08,                //       Usage Page (LEDs)
    0x09, 0x4B,                //       Usage (Generic Indicator)
    0x79, USBD_STR_LED_CENTER, //       String Index
    0x75, 0x08,                //       Report Size (8)
    0x95, 0x01,                //       Report Count (1)
    0x91, 0x02, //       Output (Data,Var,Abs,No Wrap,Linear,Preferred State,No Null Position,Non-volatile)
    0xC0,       //     End Collection

    0x05, 0x0A,               //     Usage Page (Ordinal)
    0x09, 0x06,               //     Usage (0x06)
    0xA1, 0x02,               //     Collection (Logical)
    0x05, 0x08,               //       Usage Page (LEDs)
    0x09, 0x4B,               //       Usage (Generic Indicator)
    0x79, USBD_STR_LED_RIGHT, //       String Index
    0x75, 0x08,               //       Report Size (8)
    0x95, 0x01,               //       Report Count (1)
    0x91, 0x02, //       Output (Data,Var,Abs,No Wrap,Linear,Preferred State,No Null Position,Non-volatile)
    0xC0,       //     End Collection
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

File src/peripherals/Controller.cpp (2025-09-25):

#include "peripherals/Controller.h"

#include "hardware/gpio.h"
#include "pico/time.h"

namespace Dancecon::Peripherals {

Controller::Button::Button(const uint8_t pin) : m_gpio_pin(pin), m_gpio_mask(1 << pin) {}

void Controller::Button::setState(const bool state, const uint8_t debounce_delay) {
    if (m_active == state) {
        return;
    }

    // Immediately change the input state, but only allow a change every debounce_delay milliseconds.
    const uint32_t now = to_ms_since_boot(get_absolute_time());
    if (m_last_change + debounce_delay <= now) {
        m_active = state;
        m_last_change = now;
    }
}

Controller::InternalGpio::InternalGpio(const std::map<Id, Button> &buttons) {
    for (const auto &button : buttons) {
        gpio_init(button.second.getGpioPin());
        gpio_set_dir(button.second.getGpioPin(), (bool)GPIO_IN);
        gpio_pull_up(button.second.getGpioPin());
    }
}

uint32_t Controller::InternalGpio::read() { return ~gpio_get_all(); }

Controller::ExternalGpio::ExternalGpio(const Config::ExternalGpio &config)
    : m_mcp23017(config.i2c.address, config.i2c.block) {
    m_mcp23017.setDirection(0xFFFF);       // All inputs
    m_mcp23017.setPullup(0xFFFF);          // All on
    m_mcp23017.setReversePolarity(0xFFFF); // All reversed
}

uint32_t Controller::ExternalGpio::read() { return m_mcp23017.read(); }

void Controller::socdClean(Utils::InputState &input_state) {
    auto &controller = input_state.controller;

    // Last input has priority
    if (controller.dpad.up && controller.dpad.down) {
        if (m_socd_state.lastVertical == Id::DOWN) {
            controller.dpad.down = false;
        } else if (m_socd_state.lastVertical == Id::UP) {
            controller.dpad.up = false;
        }
    } else if (controller.dpad.up) {
        m_socd_state.lastVertical = Id::UP;
    } else {
        m_socd_state.lastVertical = Id::DOWN;
    }

    if (controller.dpad.left && controller.dpad.right) {
        if (m_socd_state.lastHorizontal == Id::RIGHT) {
            controller.dpad.right = false;
        } else if (m_socd_state.lastHorizontal == Id::LEFT) {
            controller.dpad.left = false;
        }
    } else if (controller.dpad.left) {
        m_socd_state.lastHorizontal = Id::LEFT;
    } else {
        m_socd_state.lastHorizontal = Id::RIGHT;
    }
}

Controller::Controller(const Config &config) : m_config(config) {
    m_buttons.emplace(Id::UP, config.pins.dpad.up);
    m_buttons.emplace(Id::DOWN, config.pins.dpad.down);
    m_buttons.emplace(Id::LEFT, config.pins.dpad.left);
    m_buttons.emplace(Id::RIGHT, config.pins.dpad.right);
    m_buttons.emplace(Id::NORTH, config.pins.buttons.north);
    m_buttons.emplace(Id::EAST, config.pins.buttons.east);
    m_buttons.emplace(Id::SOUTH, config.pins.buttons.south);
    m_buttons.emplace(Id::WEST, config.pins.buttons.west);
    m_buttons.emplace(Id::L, config.pins.buttons.l);
    m_buttons.emplace(Id::R, config.pins.buttons.r);
    m_buttons.emplace(Id::START, config.pins.buttons.start);
    m_buttons.emplace(Id::SELECT, config.pins.buttons.select);
    m_buttons.emplace(Id::HOME, config.pins.buttons.home);
    m_buttons.emplace(Id::SHARE, config.pins.buttons.share);

    std::visit(
        [this](auto &&config) {
            using T = std::decay_t<decltype(config)>;

            if constexpr (std::is_same_v<T, Config::InternalGpio>) {
                m_gpio = std::make_unique<InternalGpio>(m_buttons);
            } else if constexpr (std::is_same_v<T, Config::ExternalGpio>) {
                m_gpio = std::make_unique<ExternalGpio>(config);
            } else {
                static_assert(false, "Unknown GPIO type!");
            }
        },
        m_config.gpio_config);
}

void Controller::updateInputState(Utils::InputState &input_state) {
    const uint32_t gpio_state = m_gpio->read();

    for (auto &button : m_buttons) {
        button.second.setState((bool)(gpio_state & button.second.getGpioMask()), m_config.debounce_delay_ms);
    }

    auto &controller = input_state.controller;
    controller.dpad.up = m_buttons.at(Id::UP).getState();
    controller.dpad.down = m_buttons.at(Id::DOWN).getState();
    controller.dpad.left = m_buttons.at(Id::LEFT).getState();
    controller.dpad.right = m_buttons.at(Id::RIGHT).getState();
    controller.buttons.north = m_buttons.at(Id::NORTH).getState();
    controller.buttons.east = m_buttons.at(Id::EAST).getState();
    controller.buttons.south = m_buttons.at(Id::SOUTH).getState();
    controller.buttons.west = m_buttons.at(Id::WEST).getState();
    controller.buttons.l = m_buttons.at(Id::L).getState();
    controller.buttons.r = m_buttons.at(Id::R).getState();
    controller.buttons.start = m_buttons.at(Id::START).getState();
    controller.buttons.select = m_buttons.at(Id::SELECT).getState();
    controller.buttons.home = m_buttons.at(Id::HOME).getState();
    controller.buttons.share = m_buttons.at(Id::SHARE).getState();

    socdClean(input_state);
}
} // namespace Dancecon::Peripherals

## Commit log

2025-09-16 Add DanceConIO pcb
    [DanceConIO.kicad_pcb, DanceConIO.kicad_sch]
2025-09-16 Add pad calibration
2025-09-16 Add Pad Buttons
2025-09-16 Add LoadCellAdapter PCB
    [LoadCellAdapter.kicad_pcb, LoadCellAdapter.kicad_sch]
2025-09-16 Add support for internal ADC
2025-09-16 Add support for on-board status led
2025-09-18 Add button mappings for remaining modes
2025-09-21 Add sample rate measurements
2025-09-21 Expose status led via HID lights
2025-09-21 Expose ADC sample rate, gain and filter in config
2025-09-25 Fix PS3 Dance Pad mode
    [StatusLed.cpp]
